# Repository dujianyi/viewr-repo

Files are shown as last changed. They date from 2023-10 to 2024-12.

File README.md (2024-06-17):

Visual, In-Expensive Wireless Rheometer (VIEWR)
=====================

Visual, In-Expensive Wireless Rheometer (VIEWR) is a low-cost (approx. $200), easy-to-deploy and versatile rheological measurement system. It is designed to measure the rheological behavior of materials and fluids in real-time, with high accuracy and precision. VIEWR is a wireless rheometer that can be used for a wide range of applications, including transient and steady shear flow characterization (viscosity and relaxation time), particle image velocimetry (PIV), extensional rheology (access to a delicate SLA or DMD printing facility required). The capability of in-situ observation allows for real-time measurement of the flow-structure interaction (FSI).

VIEWR can be used for long-term flow study of complex biological systems, such as cells, tissues and bioinks under stringent conditions, such as in an incubator or in a biosafety cabinet. VIEWR is manufactured from off-the-shelf and 3D printed components, and can be easily replicated to constitute a high-throughput measurement assay.

This repository hosts the up-to-date commits for Visual, In-Expensive Wireless Rheometer (VIEWR) with bug fixing and added features. Refer to the Wiki page for detailed instructions and specifications. 

The old repository is hosted on [OSF](https://osf.io/wj62b/) with necessary files and instructions for the VIEWR in publication[^1], but is in the process of deprecation. 



# Installation and configuration

A step-by-step installation and configuration tutorial is available on the Wiki page. Additional technical details regarding to the demonstrated material systems and experimental protocols are available in the publication[^1]. 

References
------------
[^1]: Jianyi Du, Stacey Lee, Soham Sinha, Fredrik S. Solberg, Debbie L. L. Ho, Joshua P. Sampson, Qiuling Wang, Tony Tam, Mark A. Skylar‐Scott. “A Visual, In‐Expensive, and Wireless Capillary Rheometer for Characterizing Wholly‐Cellular Bioinks”, Small, 2023, 20, 17.

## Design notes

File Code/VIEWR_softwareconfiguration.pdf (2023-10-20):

VIEWR: A Visual, InExpensive and Wireless Rheometer (Software Configuration)

Jianyi Du
Stanford University
September 27, 2023

Download the Code, Interface (optional) and VIEWRUserData folder from the permanent project repository on OSF: https://osf.io/wj62b/

Part 1: Configuration of Hardware (ESP-32 board)

1. Installation of Arduino IDE from here (https://www.arduino.cc/en/software)
a. Install ESP32 boards manager by going to:
- Open File () – Preferences (Windows) | Arduino – Settings (Mac)
- Add the following URL to the “Additional boards manager”: https://raw.githubusercontent.com/espressif/arduino-esp32/ghpages/package_esp32_index.json (https://raw.githubusercontent.com/espressif/arduino-esp32/gh-pages/package_esp32_index.json)
- Connect the ESP32 board via a micro-USB cable.
- Choose the right port/board by going to Tools - Board (ESP32 - NodeMCU-32S) or Tools – Port
If you cannot see the port, please go to this link (https://www.silabs.com/developers/usb-to-uart-bridge-vcp-drivers?tab=downloads) to download and install the latest driver for the ESP32 board, and restart Arduino IDE.
If you cannot find the ESP32 option in the Broad list, go to Board
Manager (Tools – Board:xxx – Board Manager) and search “esp32”, download the board manually (esp32 by Espressif Systems)
b. Install SubPubClient
- Open Tools - Manage Libraries
- Search PubSubClient and install
Please make sure you download the exact package as following, as there are many variants of this package.

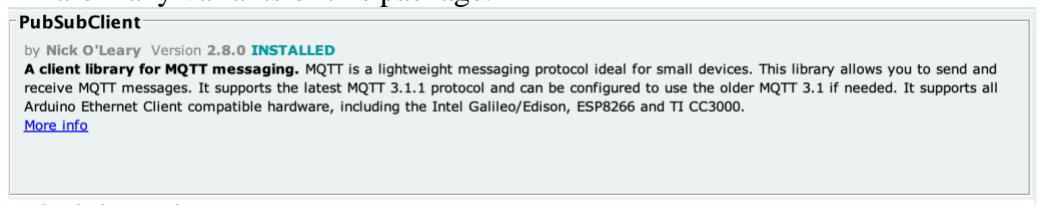
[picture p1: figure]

2. Open esp_code.ino in the Code folder with the Arduino IDE
3. Modify the Wi-Fi credentials in the esp_code.ino file
If a common router is used | Use the SSID / password for the router
If a hotspot is set up from Raspberry Pi (using dnsmcq and hostapd following this (https://www.tomshardware.com/how-to/raspberry-pi-access-point) article) | Use the specified SSID / password set from the configuration step

If a personal hotspot is set up

(using a Wi-Fi dongle, or creating from PC/phone)

Use the SSID and password for the hotspot

How to create hotspots from PC
Windows: “Network & Internet settings” - “Mobile hotspot”. For newer models, users can still connect to the Internet while using the software.
Mac: “System Setting” - “General” - “Internet sharing”. Users will not be able to connect to the Internet while using the software.
4. Modify the MQTT configuration using the host intranet IP address. You can check this using ifconfig (Mac) or ipconfig (Windows) from the command line. The IP address should be in the format of 192.168.xx.xx.
In Windows, the hostname for the IP address we need is usually named “Wireless LAN adapter local Area Connection …”

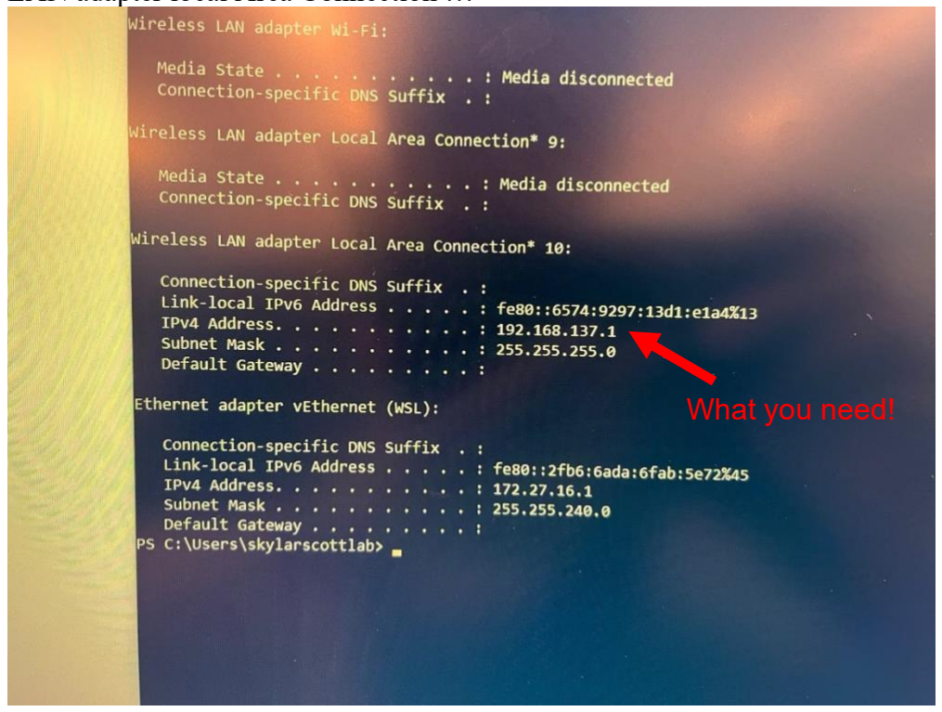
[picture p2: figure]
What you need!

5. Make sure the Wi-Fi connection is established before loading the .ino firmware file
6. Load the firmware to the ESP32 board by clicking Upload ( )button

Part 2: Configuration of Interface from Docker Image

This method using Docker image is for EZ installation of the SLA printer interface, which does not require the installation of Node-RED or any local configurations.

A little intro of Docker: Docker is a software-distribution platform using OS-level virtualization to create environments with necessary dependencies. In short, software on Docker is distributed in the form of a virtual environment (called “Images”). Users can create instances of an Image on their local environment (called “Containers”) for plug-and-play software executions, and the file systems created by Containers are fully independent of the user’s local file system.

Prerequisite for Docker image
- PC/Mac that can install Docker
- Capability to set up a personal hotspot (with internal WiFi or USB WiFi dongle)
- >2GB free space

First-time configuration
1. Install Docker: https://www.docker.com/products/personal/
2. Run Docker Desktop
For Windows users: If meeting the error of “Docker Desktop requires a newer WSL kernel version”, type
wsl –update
in Windows PowerShell first to update the environment
3. Open Windows PowerShell (Windows) or Terminal (mac)
Both shell environments are case sensitive for the inputs. Mind the case in the following prompts
4. Create a Docker network to allow communications among multiple Containers by typing
docker network create iot
This is necessary for the crosstalk between MQTT server and the interface
If meeting “error during connect: This error may indicate that the docker daemon is not running, …”: You need to wait until the Docker Desktop fully opens and initializes
5. Create a mosquito Container to support MQTT communications by typing
docker run -itd --network iot -p 1883:1883 --name mybroker eclipse-mosquitto mosquitto -c /mosquitto-no-auth.conf
6. Check if mosquitto is successfully setup and running by typing
docker logs -f mybroker
If you see “mosquitto version x.x.xx running”, the MQTT channel is successfully set up
7. Press “Ctrl/Control+C” to return the command line interface
8. Copy the VIEWRUserData folder from the Code folder to the target data folder
9. cd into the new VIEWRUserData by typing
cd [path-to-data-folder]/VIEWRUserData
Make sure to use the correct “/” or “\” on different OS
- Backslash on Windows: C:\Users\xxx\VIEWR\
- Slash on Mac: /Users/xxx/VIEWR/
10. Create Container of the VIEWR interface by typing docker run -itd -p 1880:1880 --env-file env.list --network iot -v [path-to-data-folder]/VIEWRUserData:/Data --name dockerviewr dujianyivapor/node-red-docker-viewr:latest Please make sure you are in the VIEWRUserData folder for the creation of Container, because the env.list file is necessary to set the environment for the interface
Only absolute path is legal input when specifying the folder location to avoid ambiguity. If you don’t know the absolute path of the current folder, you can use pwd If the file path contains spaces, you should replace with “_” (Windows) or prefix with “\” (Mac) to legalize the input. For example (xxx\User Files)
Windows: xxx\User_Files
Mac: xxx/User\ Files
10. At this moment the software should have been loaded. Check the status by
docker logs -f dockerviewr
You should see “Connected to broker: mqtt://mybroker:1883”
11. Open the VIEWR interface from any web browser (Safari/Chrome/Edge) at
localhost:1880/ui
You should see this interface as below

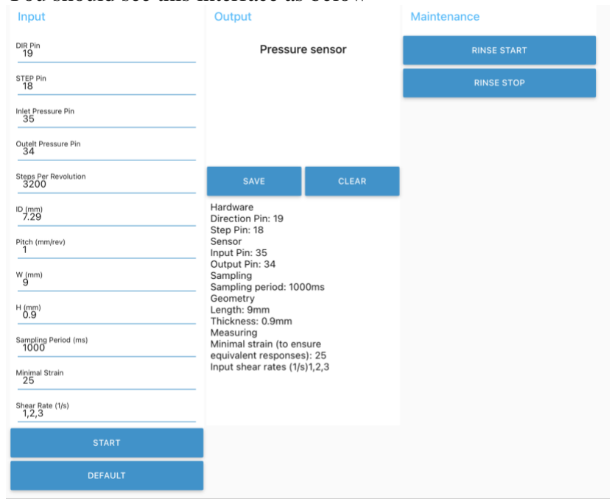
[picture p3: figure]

Reaccess after installation
1. Once the Docker Image is set up, you can simply open the software again by clicking the “Run” button (see below), followed by Step 11 above

You will need to run mybroker first and then dockerviewr

In case of software update
1. Go to Docker Desktop

2. Stop dockerviewr and delete it (it won’t affect your local files)
3. Go to “Image” tab: Delete the “dujianyivapor/node-red-docker-viewr” image
4. Repeat Step 9-11 in First-time configuration

FAQs:
Q: Setup hotspot on Windows
A: www.appuals.com/we-cant-set-up-mobile-hotspot-error-on-windows-10/

Q: MQTT not connected in Arduino Serial Monitor
A: Make sure -p 1883:1883 is added when creating the broker in Docker (Step 5 of First-time configuration)

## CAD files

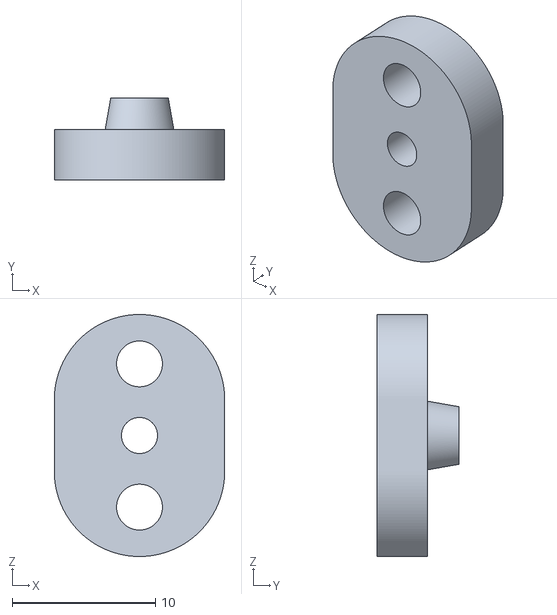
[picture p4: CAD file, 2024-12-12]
CAD/channelHolder_ID2mm_InnerRing9262K131.stl
11.9 x 5.70 x 16.9

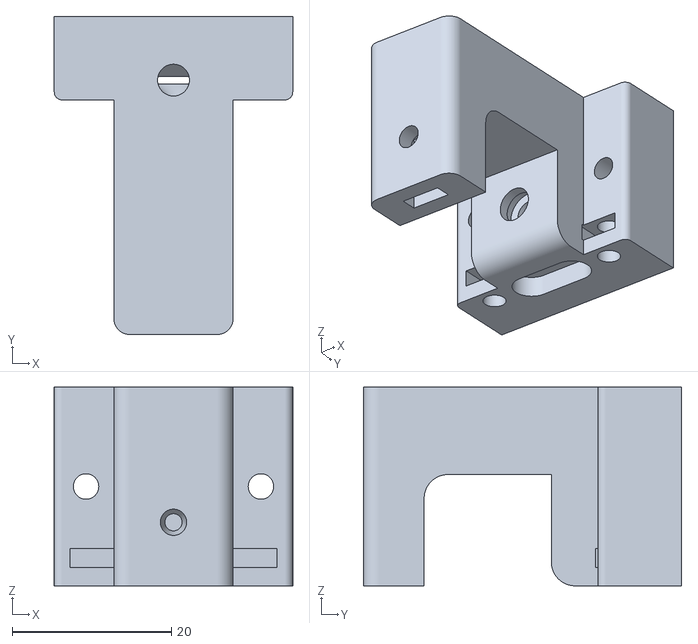
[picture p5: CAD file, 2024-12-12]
CAD/inOutletTower_M3tube_rectangularChannel_9x0.9.stl
30.0 x 40.0 x 25.0

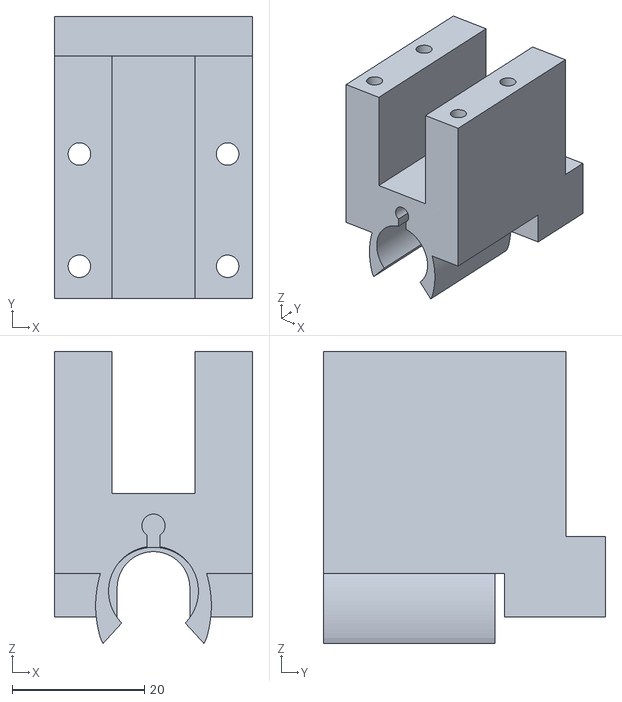
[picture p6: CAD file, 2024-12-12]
CAD/syringeHolder.stl
30.0 x 42.8 x 44.2

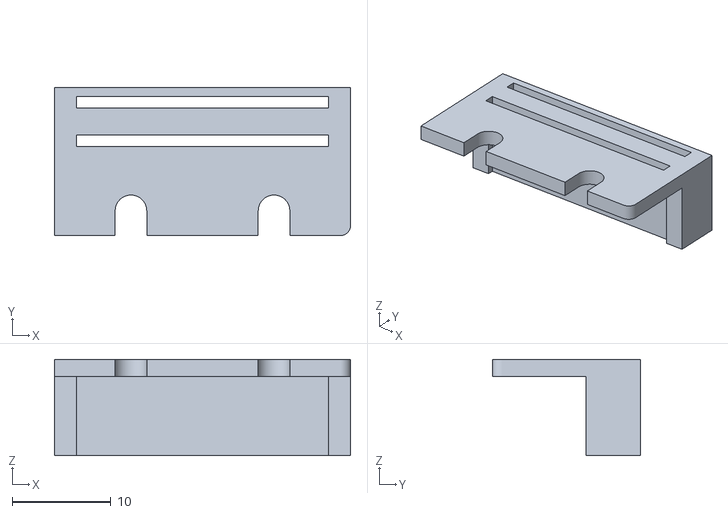
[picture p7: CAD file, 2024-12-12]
CAD/RImatching_holder.stl
30.0 x 15.0 x 9.75

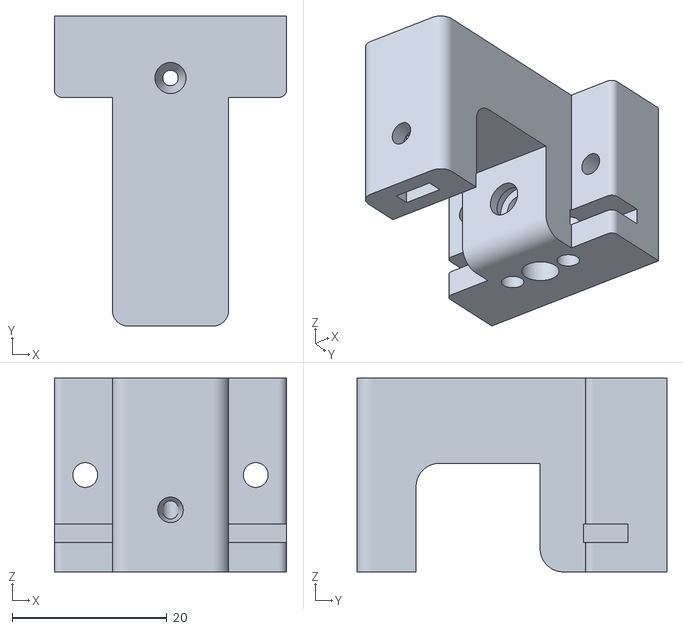
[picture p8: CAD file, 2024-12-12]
CAD/inOutletTower_M3tube_circularChannel_ID2mm.stl
30.0 x 40.0 x 25.0

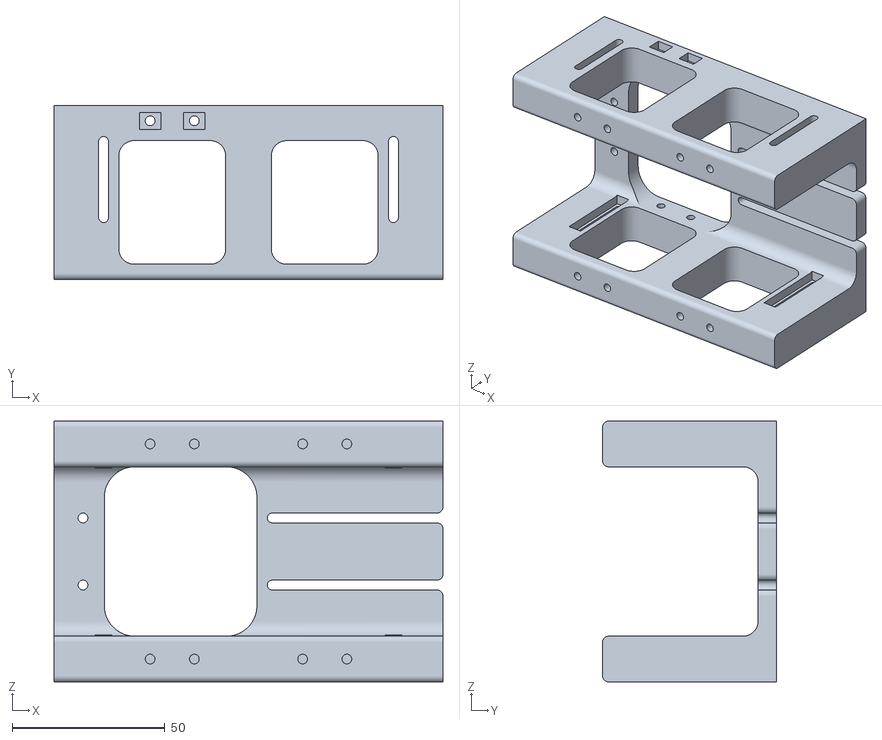
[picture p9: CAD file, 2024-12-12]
CAD/base.stl
127.5 x 57.0 x 85.5

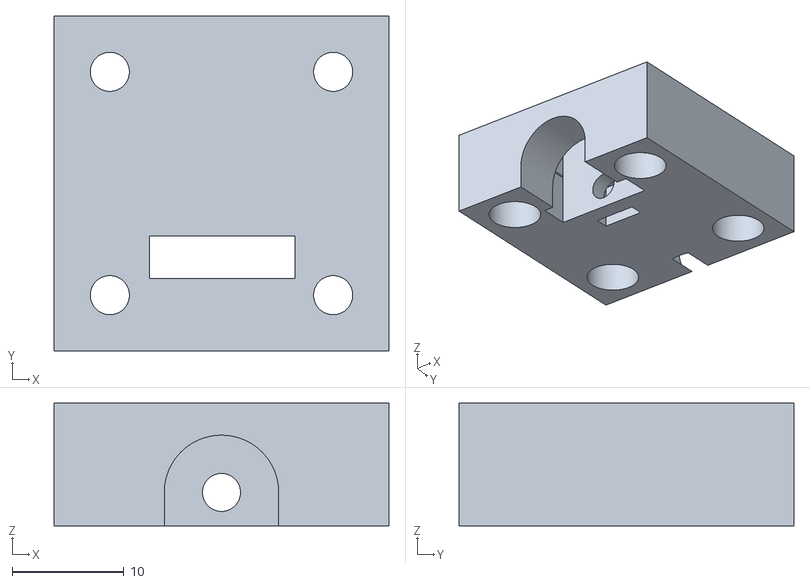
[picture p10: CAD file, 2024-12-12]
CAD/plungerHolder.stl
30.0 x 30.0 x 11.0

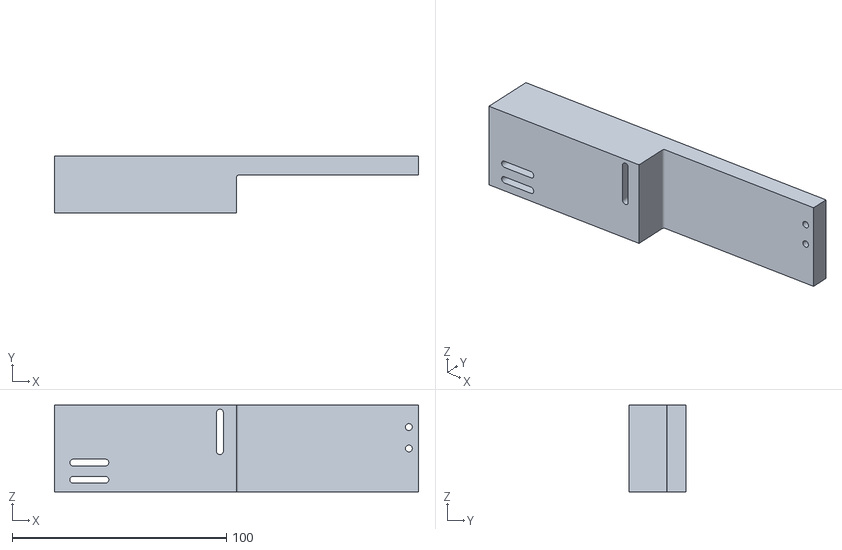
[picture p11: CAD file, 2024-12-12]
CAD/connectorBaseSyringe.stl
170.0 x 26.7 x 40.5

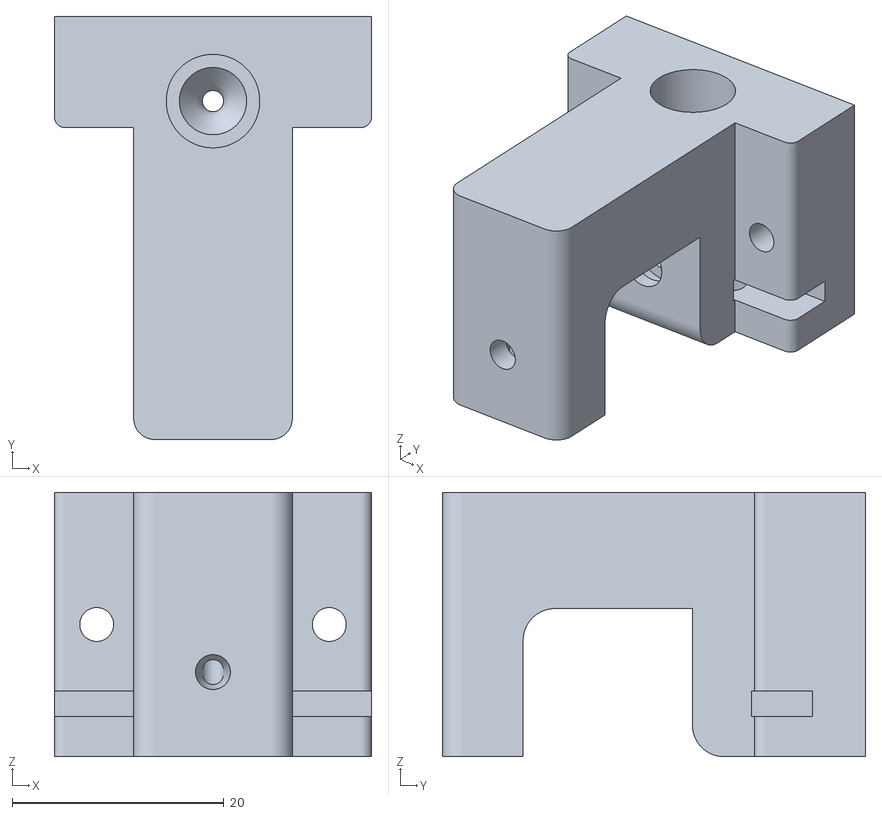
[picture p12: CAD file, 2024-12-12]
CAD/inOutletTower_1-4tube_circularChannel_ID2mm.stl
30.0 x 40.0 x 25.0

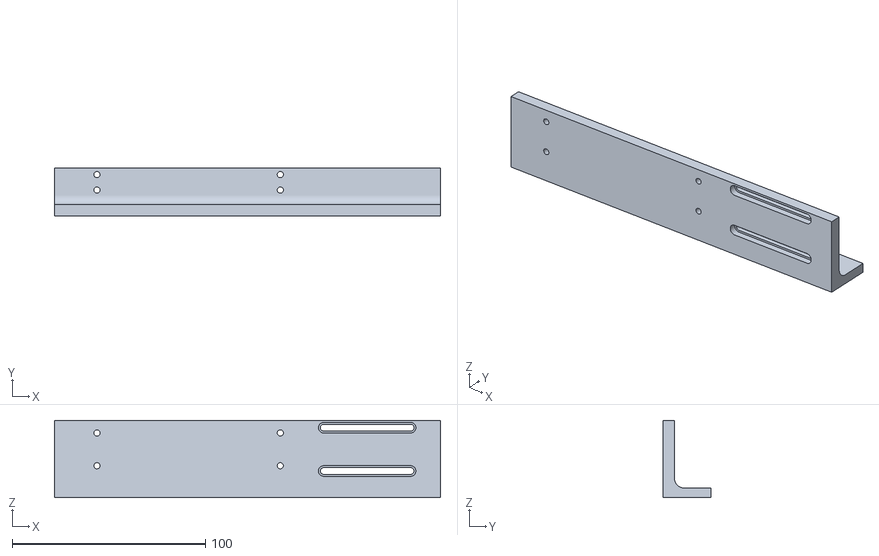
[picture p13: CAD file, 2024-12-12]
CAD/pumpBase.stl
200.0 x 25.0 x 40.0

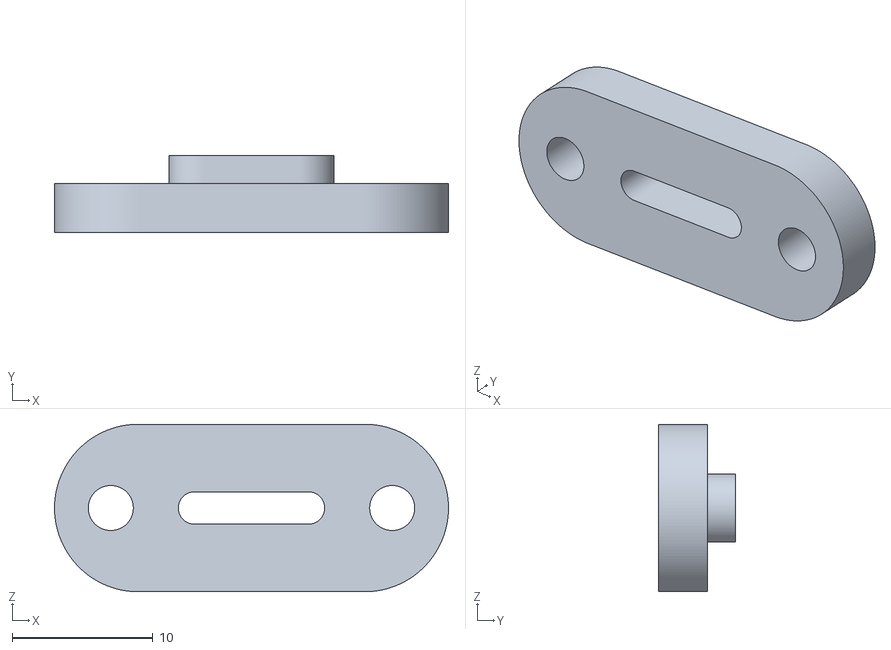
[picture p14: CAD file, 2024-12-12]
CAD/channelHolder-9x0.9.stl
28.0 x 5.50 x 11.9

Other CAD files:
CAD/inOutletTower_1-4tube_rectangularChannel_9x0.9.stl

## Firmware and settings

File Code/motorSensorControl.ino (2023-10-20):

// --------------------------------------------------------------------------- //
// --------------------------------------------------------------------------- //
// ----         __   __   ________  ______   __ __ __   ______            ---- //
// ----        /_/\ /_/\ /_______/\/_____/\ /_//_//_/\ /_____/\           ---- //
// ----        \:\ \\ \ \\__.::._\/\::::_\/_\:\\:\\:\ \\:::_ \ \          ---- //
// ----         \:\ \\ \ \  \::\ \  \:\/___/\\:\\:\\:\ \\:(_) ) )_        ---- //
// ----          \:\_/.:\ \ _\::\ \__\::___\/_\:\\:\\:\ \\: __ `\ \       ---- //
// ----           \ ..::/ //__\::\__/\\:\____/\\:\\:\\:\ \\ \ `\ \ \      ---- //
// ----            \___/_( \________\/ \_____\/ \_______\/ \_\/ \_\/      ---- //
// ----                                                                   ---- //
// ----                                                     v.0.1         ---- //
// --------------------------------------------------------------------------- //
// --------------------------------------------------------------------------- //

// +++++++++++++++++++++++++++++++++++++++++++++++++++++++++++++++++++++++++++ //

// ----- Filename ----- // 
// ++ motorSensorControl
// -------------------- // 

// ----- Description ----- // 
// ++ Configuration code to preload to microcontroller to initiate WiFi/MQTT and specify pinout information.                                             //
// ----------------------- // 

// ----- Prerequisite packages ----- // 
// ++ esp32 (board manager): See tutorials https://randomnerdtutorials.com/installing-the-esp32-board-in-arduino-ide-windows-instructions/
// ++ PubSubClient
// ++ BufferedOutput
// ++ MillisDelay
// --------------------------------- // 

// ----- Configuration ----- // 
// ++ User-based configuration is only needed in the parameter setting section. Codes following this section shall NOT be modified.
// ++ See comments after each variable for more information. 
// ------------------------- // 

// ----- Author ----- // 
// ++ Jianyi Du, Piled Higher and Deeper
// ++ Stanford University
// ++ Sept 2022
// ----------------- // 

// ----- License ----- // 
// ++ CC BY-NC-SA 4.0
// ++ (a.k.a you are free to use, modify and redistribute as long as not using for commercials, keep the same license for the redistribution and cite me)
// ----------------- // 

// ------------------------------------ Header files (NO MODIFICATIONS) ----------------------------------- //
#include <WiFi.h>
#include <PubSubClient.h>
#include <millisDelay.h>
#include <BufferedOutput.h>

// ---------------------------- User-defined parameters (MODIFICATIONS NEEDED) ---------------------------- //

// ----- Note:
// ++ These parameters are the default values onlyZ. Real values can be modified in the Node-RED interface.
// ++ Refer to Table 4 for more information. 

int dirPin = 19;                         // pinout for DIR of A4988 driver
int stepPin = 18;                        // pinout for STEP of A4988 driver 
int pPinIn = 34;                         // pinout for analog input of inlet pressure sensor
int pPinOut = 35;                        // pinout for analog input of outlet pressure sensor
int stepsPerRevolution = 3200;           // steps per revolution for stepper motor, reconfigured by MS1/2/3 on the A4988 driver
int sampleTimeGap = 100;                 // time gap for pressure sensor reading, unit in ms
double ID = 7.29;                        // inner diameter of the syringe, unit in mm
double pitchL = 1.00;                    // pitch length (distance in z per rotation on the linear rail)
double L = 9.0;                          // inner width of the capillary channel, unit in mm
double H = 0.9;                          // inner height of the capillary channel, unit in mm
double minimalStrain = 25.0;             // minimal strain or time for each shear rate
double sr = 0;                           // initial shear rate; put 0 as a safe value, unit in 1/s
int dir = 1;                             // 1 corresponds to forward (extrusion) direction for the syringe; only change if needed
unsigned long nowTime;


const char* ssid = "xxx";                // SSID for the WiFi hotspot 
const char* password = "wantSensors";    // password for the WiFi hotspot
const char* mqtt_server = "192.168.4.1"; // IP address of the host server where hotspot is created and Node-RED is running


// ------------------------------------- NO MODIFICATIONS NEEDED BELOW ------------------------------------ //

createBufferedOutput(bufferedOut, 80, DROP_UNTIL_EMPTY);
millisDelay analogInputDelay;
WiFiClient espClient;
PubSubClient client(espClient);

long now = millis();
long lastMeasure = 0;

void setup_wifi() {
  delay(10);
  Serial.println();
  Serial.print("Connecting to ");
  Serial.println(ssid);
  WiFi.begin(ssid, password);
  while (WiFi.status() != WL_CONNECTED) {
    delay(500);
    Serial.print(".");
  }
  Serial.println("");
  Serial.print("WiFi connected - ESP IP address: ");
  Serial.println(WiFi.localIP());
}

void callback(String topic, byte* message, unsigned int length) {
  Serial.print("Message arrived on topic: ");
  Serial.print(topic);
  Serial.print(". Message: ");
  String messageTemp;
  
  for (int i = 0; i < length; i++) {
    Serial.print((char)message[i]);
    messageTemp += (char)message[i];
  }
  Serial.println();

  if(topic=="motor/config/pin"){
      Serial.print("Motor dir/step pins: ");
      Serial.print(messageTemp);
      int mlen = messageTemp.length();
      int index = messageTemp.indexOf(' ', 0);
      dirPin = messageTemp.substring(0, index).toInt();
      stepPin = messageTemp.substring(index, length).toInt();
      pinMode(dirPin, OUTPUT);
      pinMode(stepPin, OUTPUT);
  }
  Serial.println();

  if(topic=="motor/config/step"){
      Serial.print("Step per revolution: ");
      Serial.print(messageTemp);
      stepsPerRevolution = messageTemp.length();
  }
  Serial.println();

  // motor pins config
  if(topic=="psensor/config/pin"){
      Serial.print("Pressure Sensor Pin: ");
      Serial.print(messageTemp);
      int mlen = messageTemp.length();
      int index = messageTemp.indexOf(' ', 0);
      pPinIn = messageTemp.substring(0, index).toInt();
      pPinOut = messageTemp.substring(index, length).toInt();
  }
  Serial.println();

  // geometry config/channel 
  if(topic=="geometry/config/channel"){
      Serial.print("Geometry dimension: ");
      Serial.print(messageTemp);
      int mlen = messageTemp.length();
      int index = messageTemp.indexOf(' ', 0);
      L = messageTemp.substring(0, index).toInt();
      H = messageTemp.substring(index, length).toInt();
  }
  Serial.println();

  // geometry config/device 
  if(topic=="geometry/config/device"){
      Serial.print("ID (mm) / Pitch (mm/rev): ");
      Serial.print(messageTemp);
      int mlen = messageTemp.length();
      int index = messageTemp.indexOf(' ', 0);
      ID = messageTemp.substring(0, index).toDouble();
      pitchL = messageTemp.substring(index, length).toDouble();
  }
  Serial.println();

  // runtime config/sampling
  if(topic=="runtime/config/sampling"){
      Serial.print("Sampling time period (ms): ");
      Serial.print(messageTemp);
      sampleTimeGap = messageTemp.toInt();
  }
  Serial.println();

  // runtime config/max strain
  if(topic=="runtime/config/strain"){
      Serial.print("Minimal strain: ");
      Serial.print(messageTemp);
      minimalStrain = messageTemp.toDouble();
  }
  Serial.println();

  // This will trigger the execution
  if(topic=="runtime/srstart"){
      int mlen = messageTemp.length();
      int index = messageTemp.indexOf(' ', 0);
      sr = messageTemp.substring(0, index).toDouble();
      dir = messageTemp.substring(index, length).toInt();

      Serial.println("--- START ---");
      Serial.print("Shear rate (1/s): ");
      Serial.println(sr);
      double currentQ = H*H*L*sr/6; // mm^3/s
      Serial.print("Flow rate (mm^3/s): ");
      Serial.println(currentQ);
      double timeShear = max(minimalStrain, minimalStrain/sr);
      Serial.print("Time of shearing (s): ");
      Serial.println(timeShear);
      double speedRev = currentQ*stepsPerRevolution/pitchL/(3.1416*ID*ID/4);
      Serial.print("Speed of steps (steps/s): ");
      Serial.println(speedRev);
      Serial.println("------ Data sent to MQTT ------");

      nowTime = millis();
      analogInputDelay.start(sampleTimeGap);
      double currentX = 6521.4046875/currentQ; // microseconds
      if (dir == 1){
        digitalWrite(dirPin, HIGH);
      }else{
        digitalWrite(dirPin, LOW);
      }
      while (millis() - nowTime < timeShear*1000) {
        digitalWrite(stepPin, HIGH);
        delayMicroseconds(currentX);
        digitalWrite(stepPin, LOW);
        delayMicroseconds(currentX);
        analogInput13();
      }      
            
      client.publish("runtime/pDiff", "--- END ---");
  }
  Serial.println();
}

void reconnect() {
  // Loop until we're reconnected
  while (!client.connected()) {
    Serial.print("Attempting MQTT connection...");
    if (client.connect("ESP32Client")) {
      Serial.println("connected");  
      client.publish("status", "WiFi and MQTT connected.");
      // Subscribe or resubscribe to a topic
      client.subscribe("motor/config/pin");
      client.subscribe("motor/config/step");
      client.subscribe("psensor/config/pin");
      client.subscribe("geometry/config/channel");
      client.subscribe("geometry/config/device");
      client.subscribe("runtime/config/sampling");
      client.subscribe("runtime/config/strain");
      client.subscribe("runtime/srstart");      
    } else {
      Serial.print("failed, rc=");
      Serial.print(client.state());
      Serial.println(" try again in 5 seconds");
      // Wait 5 seconds before retrying
      delay(5000);
    }
  }
}

void setup() {  
  Serial.begin(9600);
  bufferedOut.connect(Serial);
  setup_wifi();
  client.setServer(mqtt_server, 1883);
  client.setCallback(callback);
}

void analogInput13(){
  if (analogInputDelay.justFinished()) {   // check if delay has timed out
      analogInputDelay.repeat(); // start delay again without drift
      char pinOut[100];
      int inValue = analogRead(pPinIn);
      int outValue = analogRead(pPinOut);
      sprintf(pinOut,"%i %i", inValue, outValue);
      client.publish("runtime/pDiff", pinOut);
      
    }
}

void loop() {

  if (!client.connected()) {
    reconnect();
  }
  if(!client.loop())
    client.connect("ESP32Client");

} 

// ------------------------------------- NO MODIFICATIONS NEEDED ABOVE ------------------------------------ //

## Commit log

2023-10-18 change of filename from flow to flows
2023-10-23 corrected pin numbers of pressure sensors; fixed typos; added wiki
2024-12-12 Overhauled CAD designs of inlet/outlet towers for easier installation
    [Assem.SLDASM, RImatching_holder.SLDPRT, RImatching_holder.stl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]

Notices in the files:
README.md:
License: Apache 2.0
